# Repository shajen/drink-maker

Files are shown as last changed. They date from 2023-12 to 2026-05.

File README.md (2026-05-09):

# Introduction

The project is to build a device for automatically pouring vodka into glasses that move on wooden toy tracks.

# Presentation video

Video (http://www.youtube.com/watch?v=X1K5z6y2sik "Video")

# Quickstart

## 3D files

Parts to print available [here](3d/).

## Needed hardware

- `ESP32 C3 super mini` board with Li-Ion 18650
- `ST7789` OLED 2.0" `SPI` 240x320
- `VL53L0X` time of flight distance sensor `I2C`
- `MAX17043` battery fuel gauge `I2C`
- 5 V relay module
- 5 V mini pump
- voltage divider between battery and A0
- silicone tube

## Pinout

| Description | ESP32 C3 PIN |
| --- | --- |
| I2C SCL | GPIO9 |
| I2C SDA | GPIO8 |
| Relay | GPIO0 |
| LCD CS | GPIO5 |
| LCD DC | GPIO6 |
| LCD MOSI | GPIO10 |
| LCD SCLK | GPIO1 |
| LCD RST | GPIO7 |

## Flash

```
platformio run -t buildfs
platformio run -t uploadfs
platformio run -t upload
```

## Settings

Connect your mobile phone or PC to WiFi:  
network name: `Vodka`  
password: `12345678`

Then open [http://vodka.local/](http://vodka.local/).

| | | |
| --- | --- | --- |
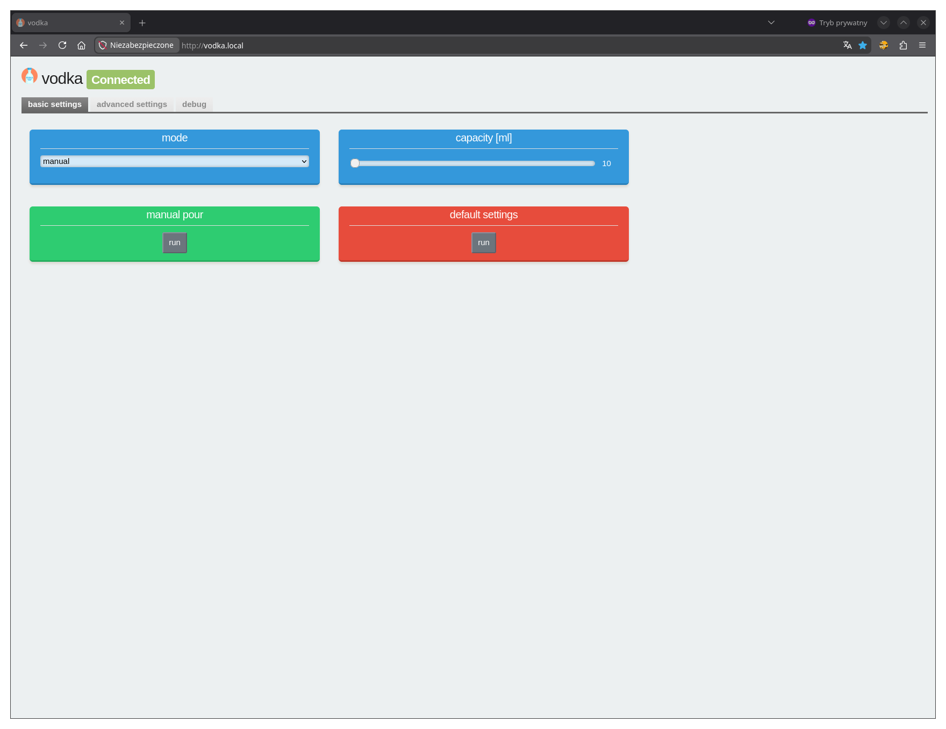
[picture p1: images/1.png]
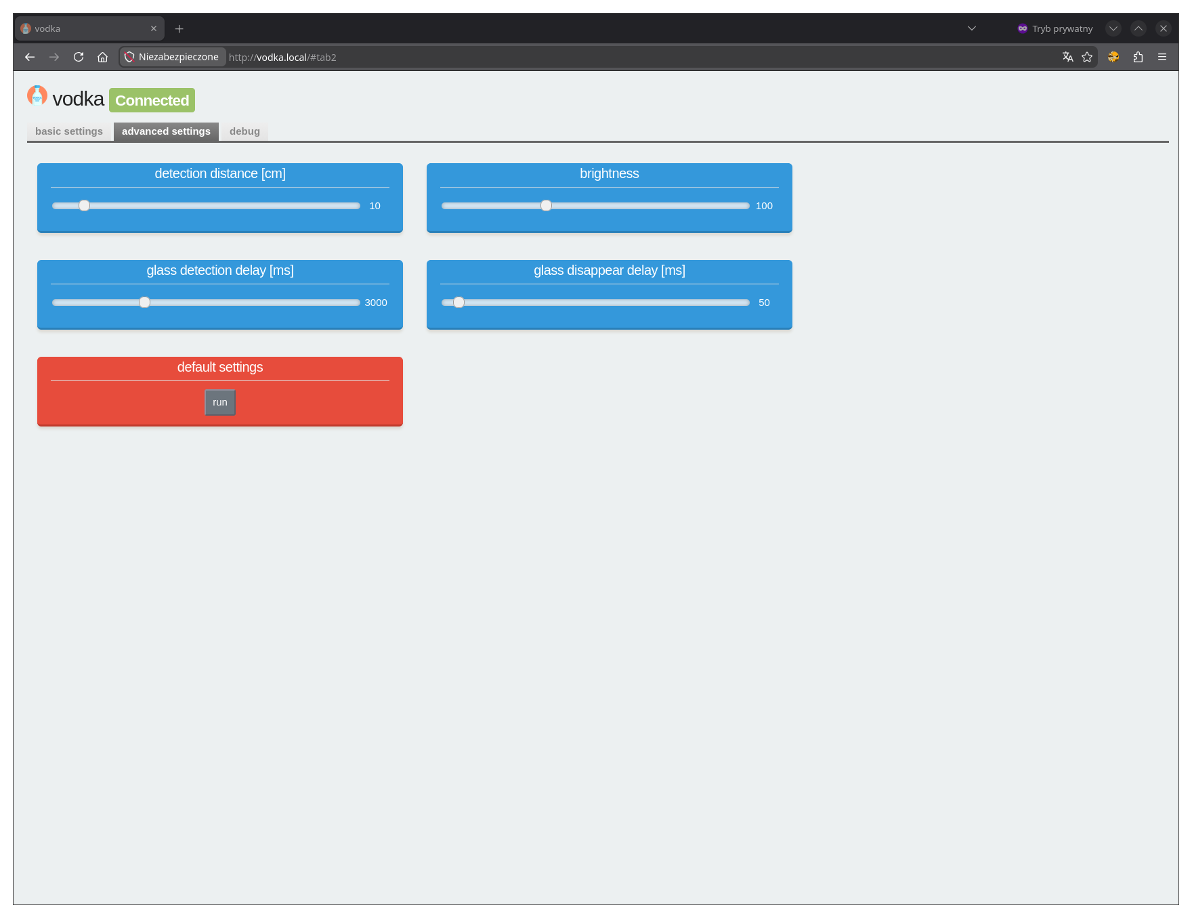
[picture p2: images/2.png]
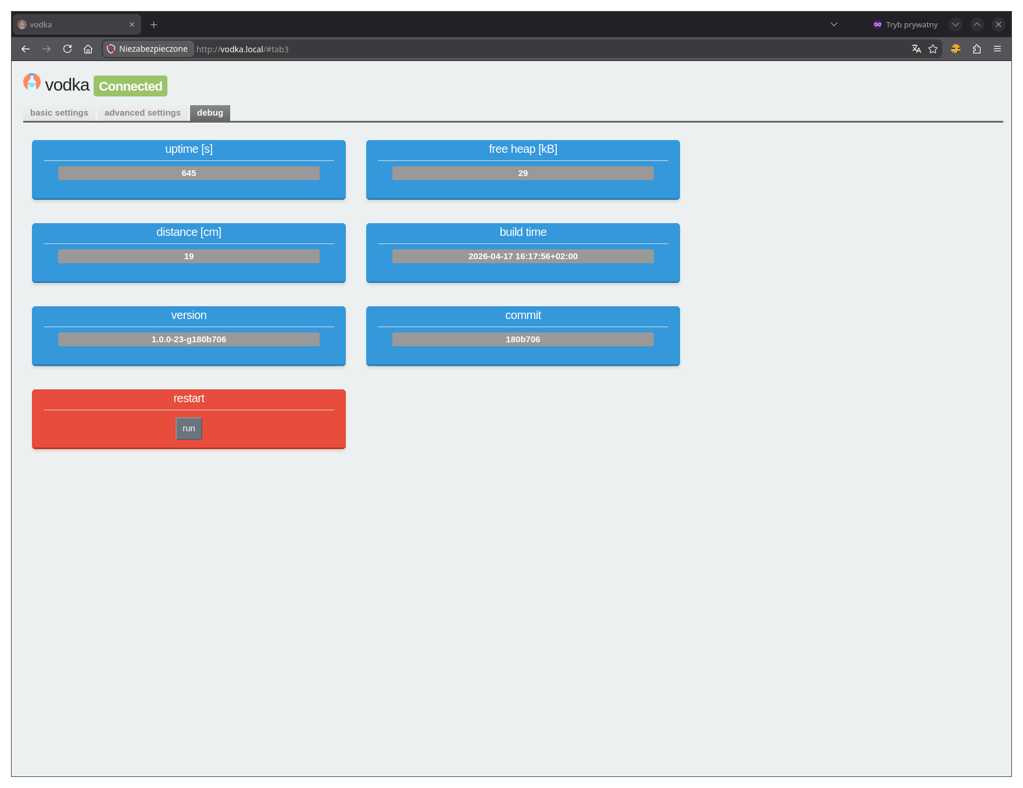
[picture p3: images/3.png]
|  |  |  |
 
# Contributing

In general don't be afraid to send pull request. Use the "fork-and-pull" Git workflow.

1. **Fork** the repo
2. **Clone** the project to your own machine
3. **Commit** changes to your own branch
4. **Push** your work back up to your fork
5. Submit a **Pull request** so that we can review your changes

NOTE: Be sure to merge the **latest** from **upstream** before making a pull request!

# Donations

If you enjoy this project and want to thanks, please use follow link:

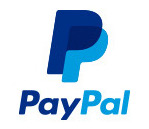
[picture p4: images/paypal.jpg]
[](https://www.paypal.com/donate/?hosted_button_id=6JQ963AU688QN)
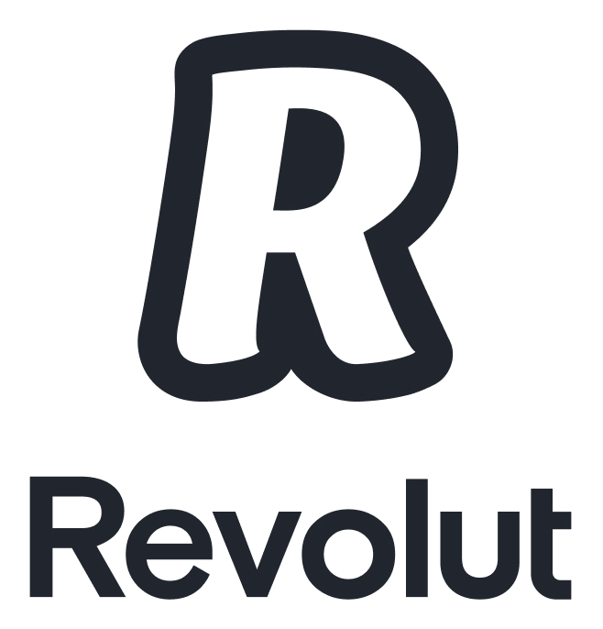
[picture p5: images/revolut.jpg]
[](https://revolut.me/borysm2b)
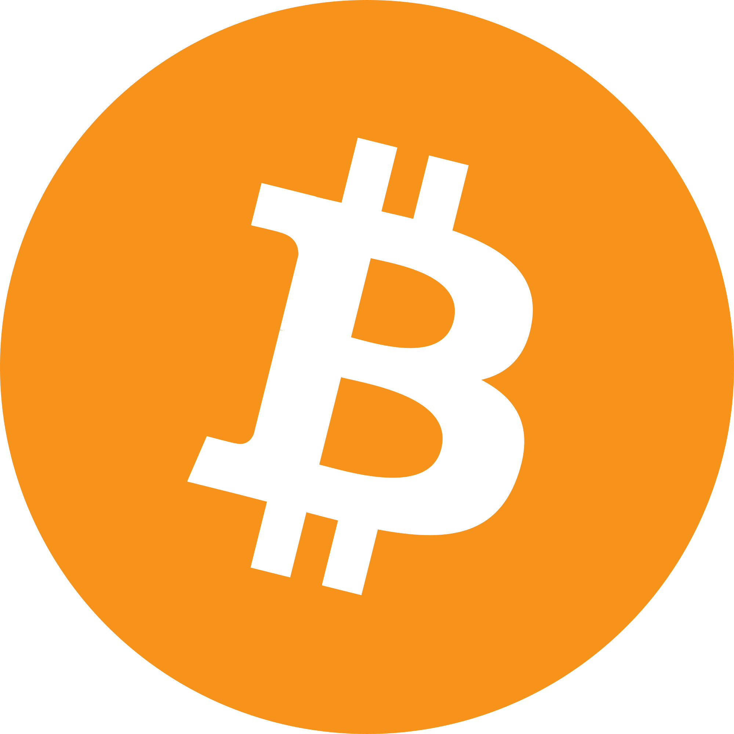
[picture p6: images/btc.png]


BTC address: 18UDYg9mu26K2E3U479eMvMZXPDpswR7Jn

# License



- *[GPLv3 license](https://www.gnu.org/licenses/gpl.html)*

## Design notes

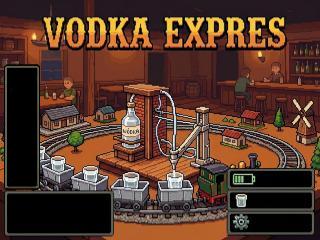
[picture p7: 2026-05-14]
images/background.jpeg

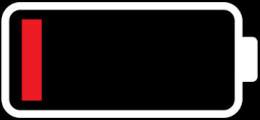
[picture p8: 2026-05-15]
images/low_battery.jpg

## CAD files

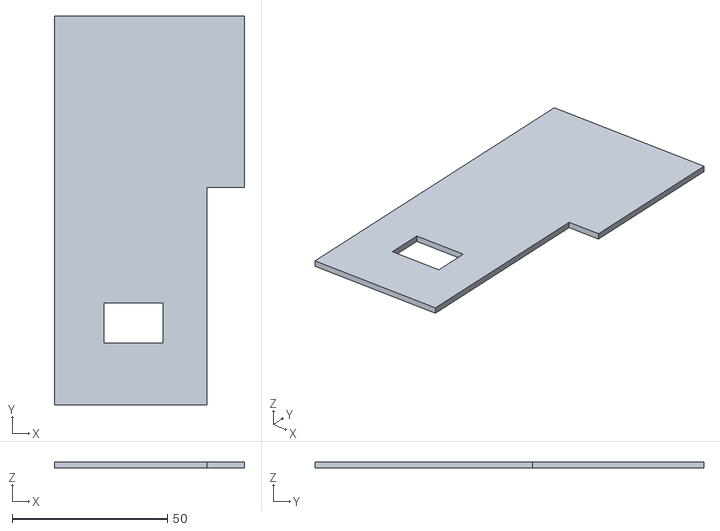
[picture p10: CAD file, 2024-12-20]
3d/drink_maker.stl
61.2 x 125.2 x 2.00

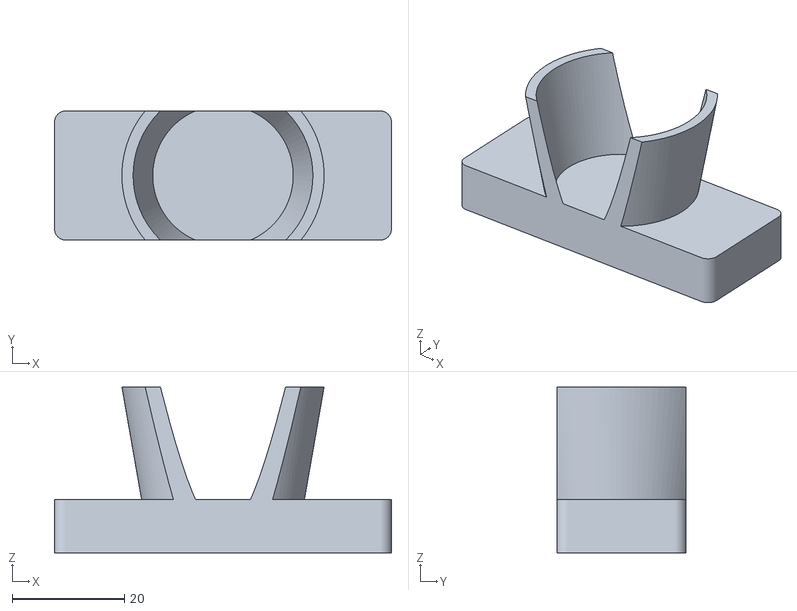
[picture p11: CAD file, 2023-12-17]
3d/wagon_container_aluminium_glass.stl
60.0 x 23.0 x 29.5

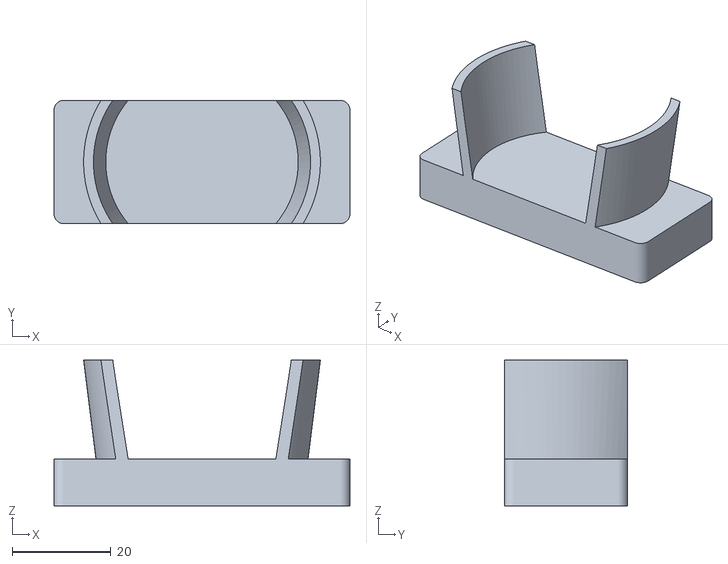
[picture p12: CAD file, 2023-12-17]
3d/wagon_container_ikea_glass.stl
60.0 x 25.0 x 29.5

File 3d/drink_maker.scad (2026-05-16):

include <pipe.scad>
include <generic.scad>
include <roundedcube.scad>
include <straigt_track.scad>

$fn = 100;
MARGIN = 0.01;
ROUND = 1.5;
WALL = 2.0;
LID_STEP = 1.0;
LID_MARGIN = 0.4;

WIDTH = 90 + 4 * WALL;
DEPTH = 120 + 4 * WALL;
HEIGHT = 52;

PIPE_IN_DIA = 6.6;
PIPE_OUT_DIA = 9.8;
PIPE_MOUNT_DIA = 10.0;
PIPE_CONNECTOR_LENGTH = 10;
PIPE_DEPTH_OFFSET = 73;
PIPE_BEND_R = 20;
PIPE_A = 110;
PIPE_B = 86;
PIPE_C = 50;

DS_DEPTH = 15;
DS_DEPTH_OFFSET = PIPE_DEPTH_OFFSET + DS_DEPTH + 5 + PIPE_MOUNT_DIA;
DS_HEIGHT = 8;
DS_HEIGHT_OFFSET = 26;

LCD_DEPTH = 52;
LCD_DEPTH_OFFSET = 22 + 18;
LCD_HEIGHT = 35.8;
LCD_HEIGHT_OFFSET = 10;

ESP_CABLE_DEPTH = 13.0;
ESP_CABLE_HEIGHT = 4.5;
ESP_CABLE_DEPTH_OFFSET = 82;
ESP_CABLE_HEIGHT_OFFSET = 36;

BASE_HEIGHT = 12;
BASE_WALL = 2;
BASE_MARGIN = 0.4;

TRACK_DISTANCE = 40;
TRACK_MARGIN = 2;

SWITCH_R = 6.4;
SWITCH_DEPTH_OFFSET = 110;
SWITCH_HEIGHT_OFFSET = 36;

MOUNTPOINT_SIZE = 6;
MOUNTPOINT_R = 1.5;
MOUNTPOINT_HEIGHT = 12;
SUPPORT_HEIGHT = 12;

PCB_MOUNTPOINT_USB_WIDTH_OFFSET = 10;
PCB_MOUNTPOINT_WIDTH_OFFSET = 43.3;
PCB_MOUNTPOINT_DEPTH_OFFSET = 28.3;
PCB_MOUNTPOINT_HEIGHT = 10;
PCB_MOUNTPOINT_BORDER_SIZE = 2;
PCB_WIDTH = 81;
PCB_DEPTH = 55.4;

BATTERY_WIDTH = 78.0;
BATTERY_DEPTH = 41.4;
BATTERY_HEIGHT = 20;
BATTERY_WALL = 2;
BATTERY_WIDTH_OFFSET = -BATTERY_WALL;
BATTERY_DEPTH_OFFSET = PCB_DEPTH;

module pcb_mountpoint(x, y, h, r1, r2) {
  translate([WALL + x, WALL + y, WALL]) {
    difference() {
      cylinder(h=h, r=r1);
      cylinder(h=h + MARGIN, r=r2);
    }
  }
}

module window(depth, height, depth_offset, height_offset) {
  translate([WALL + WIDTH - MARGIN, WALL + depth_offset - depth / 2, WALL + height_offset])
    cube([WALL + 2 * MARGIN, depth, height]);
}

module window2(depth, height, depth_offset, height_offset) {
  translate([-MARGIN, WALL + depth_offset - depth / 2, WALL + height_offset])
    cube([WALL + 2 * MARGIN, depth, height]);
}

module circle2(radius, depth_offset, height_offset) {
  translate([-MARGIN, depth_offset, height_offset + radius])
    rotate([0, 90, 0])
      cylinder(h=WALL + 2 * MARGIN, r=radius);
}

module single_support() {
  x = MOUNTPOINT_SIZE;
  h = SUPPORT_HEIGHT;
  translate([-MOUNTPOINT_SIZE / 2, -MOUNTPOINT_SIZE / 2, 0])
    polyhedron(
      points=[
        [0, 0, 0],
        [x, 0, 0],
        [0, 0, h],
        [x, 0, h],
        [x, x, h],
        [0, x, h],
      ],
      faces=[
        [0, 1, 3, 2],
        [1, 4, 3],
        [0, 5, 4, 1],
        [0, 2, 5],
        [2, 3, 4, 5],
      ],
      convexity=10
    );
}

module support(degree) {
  translate([MOUNTPOINT_SIZE / 2, MOUNTPOINT_SIZE / 2, 0]) rotate([0, 0, degree]) single_support();
  translate([MOUNTPOINT_SIZE / 2, MOUNTPOINT_SIZE / 2, 0]) rotate([0, 0, degree + 90]) single_support();
}

module mountpoint(x, y, degree) {
  translate([x + WALL, y + WALL, HEIGHT + WALL - SUPPORT_HEIGHT - MOUNTPOINT_HEIGHT]) {
    support(degree);
    translate([0, 0, SUPPORT_HEIGHT]) {
      difference() {
        cube([MOUNTPOINT_SIZE, MOUNTPOINT_SIZE, MOUNTPOINT_HEIGHT]);
        translate([MOUNTPOINT_SIZE / 2, MOUNTPOINT_SIZE / 2, 0])
          cylinder(h=MOUNTPOINT_HEIGHT + MARGIN, r=MOUNTPOINT_R);
      }
    }
  }
}

module shape(height, margin) {
  difference() {
    cube([WIDTH + 2 * margin, DEPTH + 2 * margin, height]);
    translate([WIDTH - WALL - PIPE_MOUNT_DIA + 2 * margin, PIPE_DEPTH_OFFSET + 2 * margin, -MARGIN]) cube(
        [
          PIPE_MOUNT_DIA + 2 * WALL + MARGIN + margin,
          PIPE_MOUNT_DIA + 4 * WALL - 2 * margin,
          height + 2 * MARGIN,
        ]
      );
  }
}

module main() {
  difference() {
    roundedcube([2 * WALL + WIDTH, 2 * WALL + DEPTH, 2 * WALL + HEIGHT], false, ROUND, "z");
    translate([WALL - LID_STEP, WALL - LID_STEP, WALL + HEIGHT]) shape(WALL + MARGIN, LID_STEP);
    translate([WALL, WALL, WALL]) shape(HEIGHT + WALL + MARGIN, 0);

    window(LCD_DEPTH, LCD_HEIGHT, LCD_DEPTH_OFFSET, LCD_HEIGHT_OFFSET);
    window(DS_DEPTH, DS_HEIGHT, DS_DEPTH_OFFSET, DS_HEIGHT_OFFSET);

    window2(
      ESP_CABLE_DEPTH, ESP_CABLE_HEIGHT, ESP_CABLE_DEPTH_OFFSET,
      ESP_CABLE_HEIGHT_OFFSET
    );
    circle2(SWITCH_R, SWITCH_DEPTH_OFFSET, SWITCH_HEIGHT_OFFSET);

    translate(
      [WALL + WIDTH - PIPE_MOUNT_DIA / 2, PIPE_DEPTH_OFFSET + PIPE_MOUNT_DIA / 2 + 3 * WALL, WALL + HEIGHT - PIPE_CONNECTOR_LENGTH]
    )
      pipe(0, PIPE_MOUNT_DIA, PIPE_CONNECTOR_LENGTH + WALL + MARGIN);

    translate([WIDTH - PIPE_MOUNT_DIA - MARGIN, PIPE_DEPTH_OFFSET + 3 * WALL, WALL + MARGIN])
      cube([PIPE_MOUNT_DIA + WALL, PIPE_MOUNT_DIA, HEIGHT - PIPE_CONNECTOR_LENGTH - WALL]);
  }
  mountpoint(0, 0, 270);
  mountpoint(0, DEPTH - 3 * WALL, 180);
  mountpoint(WIDTH - 3 * WALL, DEPTH - 3 * WALL, 90);
  mountpoint(WIDTH - 3 * WALL, 0, 0);

  pcb_mountpoint(PCB_MOUNTPOINT_USB_WIDTH_OFFSET + PCB_MOUNTPOINT_WIDTH_OFFSET, PCB_MOUNTPOINT_DEPTH_OFFSET, PCB_MOUNTPOINT_HEIGHT, 7, 1.5);
  translate([WALL + PCB_MOUNTPOINT_USB_WIDTH_OFFSET, WALL, WALL])
    difference() {
      cube([PCB_WIDTH, PCB_DEPTH, PCB_MOUNTPOINT_HEIGHT]);
      translate([PCB_MOUNTPOINT_BORDER_SIZE, PCB_MOUNTPOINT_BORDER_SIZE, MARGIN])
        cube([PCB_WIDTH - 2 * PCB_MOUNTPOINT_BORDER_SIZE, PCB_DEPTH - 2 * PCB_MOUNTPOINT_BORDER_SIZE, PCB_MOUNTPOINT_HEIGHT]);
    }

  translate([WALL + BATTERY_WIDTH_OFFSET, WALL + BATTERY_DEPTH_OFFSET, WALL])
    difference() {
      cube([BATTERY_WIDTH + 2 * BATTERY_WALL, BATTERY_DEPTH + 2 * BATTERY_WALL, BATTERY_HEIGHT]);
      translate([BATTERY_WALL, BATTERY_WALL, MARGIN])
        cube([BATTERY_WIDTH, BATTERY_DEPTH, BATTERY_HEIGHT]);
    }
}

module lid() {
  difference() {
    shape(WALL, LID_STEP - LID_MARGIN);
    translate([LID_STEP + MOUNTPOINT_SIZE / 2, LID_STEP + MOUNTPOINT_SIZE / 2, 0]) {
      custom_cylinder(outside_radius=1.5, height=WALL + 2 * MARGIN);
      translate([WIDTH - MOUNTPOINT_SIZE, 0])
        custom_cylinder(outside_radius=1.5, height=WALL + 2 * MARGIN);
      translate([WIDTH - MOUNTPOINT_SIZE, DEPTH - MOUNTPOINT_SIZE, 0])
        custom_cylinder(outside_radius=1.5, height=WALL + 2 * MARGIN);
      translate([0, DEPTH - MOUNTPOINT_SIZE, 0])
        custom_cylinder(outside_radius=1.5, height=WALL + 2 * MARGIN);
    }
  }
}

module base() {
  difference() {
    roundedcube(
      [WIDTH + 2 * (BASE_WALL + WALL), DEPTH + 2 * (BASE_WALL + WALL), BASE_HEIGHT + BASE_WALL], false,
      ROUND, "z"
    );
    translate([BASE_WALL - BASE_MARGIN, BASE_WALL - BASE_MARGIN, BASE_HEIGHT])
      cube([WIDTH + 2 * (BASE_MARGIN + WALL), DEPTH + 2 * (BASE_MARGIN + WALL), BASE_WALL + MARGIN]);
    translate([2 * BASE_WALL, 2 * BASE_WALL, -MARGIN])
      cube([WIDTH + 2 * (WALL - BASE_WALL), DEPTH + 2 * (WALL - BASE_WALL), BASE_HEIGHT + 2 * MARGIN]);
  }

  X = 2 * (BASE_WALL + WALL);
  TRACK_LENGTH = DEPTH + 2 * (BASE_WALL + WALL);

  translate([WIDTH + X - TRACK_MARGIN, 0, 0]) cube([TRACK_DISTANCE + 2 * TRACK_MARGIN, DEPTH + X, WALL]);
  translate([WIDTH + X + TRACK_DISTANCE, TRACK_LENGTH, 0]) rotate([0, 0, 270])
      straigt_track(TRACK_LENGTH, false, left_connector="male", right_connector="female");
}

module pipe_u() {
  X = PIPE_BEND_R + PIPE_OUT_DIA / 2;
  Y = PIPE_BEND_R + PIPE_OUT_DIA / 2;

  A = PIPE_A - Y;
  B = PIPE_B - 2 * Y;
  C = PIPE_C - Y;

  translate([PIPE_OUT_DIA / 2, 0, X]) pipe(PIPE_IN_DIA, PIPE_OUT_DIA, A);
  translate([X, 0, X]) rotate([270, 0, 180]) pipe_90(PIPE_IN_DIA, PIPE_OUT_DIA, 0, PIPE_BEND_R);
  translate([X, 0, PIPE_OUT_DIA / 2]) rotate([0, 90, 0]) pipe(PIPE_IN_DIA, PIPE_OUT_DIA, B);
  translate([X + B, 0, X]) rotate([270, 0, 0]) pipe_90(PIPE_IN_DIA, PIPE_OUT_DIA, 0, PIPE_BEND_R);
  translate([B + 2 * X - PIPE_OUT_DIA / 2, 0, X]) pipe(PIPE_IN_DIA, PIPE_OUT_DIA, C);
}

translate([0 * (WIDTH + 10), 0, 0]) main();
translate([1 * (WIDTH + 10), 0, 0]) lid();
translate([2 * (WIDTH + 10), 0, 0]) base();
translate([3 * (WIDTH + 10) + TRACK_DISTANCE + 40 + 4 * WALL, 0, 0]) pipe_u();

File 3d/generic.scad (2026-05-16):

MARGIN = 0.01;

module custom_cylinder(outside_radius, height, inside_radius = 0) {
  difference() {
    cylinder(h=height, r=outside_radius);
    if (0 < inside_radius) {
      translate([0, 0, -MARGIN])
        cylinder(h=height + 2 * MARGIN, r=inside_radius);
    }
  }
}

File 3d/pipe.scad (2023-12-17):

module pipe(inside_dia, outside_dia, height)
{
    linear_extrude(height = height, center = false) difference()
    {
        circle(r = outside_dia / 2, $fn = 100);
        circle(r = inside_dia / 2, $fn = 100);
    }
}

module pipe_90(in_dia, out_dia, length, bend_radius)
{
    X = 0; // bend_radius * sqrt(2);
    translate([ -X / 2, -X / 2, 0 ])
    {
        rotate_extrude(angle = 90, convexity = 10) translate([ bend_radius, 0, 0 ]) difference()
        {
            circle(r = out_dia / 2);
            circle(r = in_dia / 2);
        }
        translate([ -length, bend_radius, 0 ]) rotate([ 0, 90, 0 ]) pipe(in_dia, out_dia, length);
        translate([ bend_radius, 0, 0 ]) rotate([ 90, 0, 0 ]) pipe(in_dia, out_dia, length);
    }
}

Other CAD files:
3d/straigt_track.scad
3d/roundedcube.scad
3d/wagon_container.scad

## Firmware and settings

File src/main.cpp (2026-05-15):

#include <Wire.h>
#include <config.h>
#include <logger.h>
#include <low_battery_controller.h>
#include <main_controller.h>

#include <memory>

std::unique_ptr<Thread> thread;

void setup() {
  Serial.begin(UART_BAUDRATE);
  Serial.printf("\n");
  log("main", "init");
  log("main", "hostname: %s, build time: %s, version: %s, commit: %s", HOSTNAME, BUILD_TIME, GIT_TAG, GIT_COMMIT);
  Wire.begin(SDA_PIN, SCL_PIN);
  LittleFS.begin();

  BatteryController batteryController;
  if (batteryController.isLowBattery()) {
    thread = std::make_unique<LowBatteryController>();
  } else {
    thread = std::make_unique<MainController>();
  }
}

void loop() {
  delay(1);
  thread->loop(std::chrono::milliseconds(millis()));
}

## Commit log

2023-12-16 Replaced polish menu with english.
    [pouring_controller.cpp]
2023-12-17 Added 3D files.
    [drink_maker.scad, drink_maker.stl, pipe.scad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]
2024-12-20 Added switch to lid.
    [drink_maker.scad, drink_maker.stl]
2025-01-23 Removed buttons.
2025-01-28 Updated 3d model.
    [drink_maker.scad]
2025-02-11 Added manual pour button.
2025-04-01 Added battery level.
2025-04-04 Fixed initial battery voltage, made voltage reading more stable.
2025-04-09 Show battery on display.
2025-04-12 Round battery percentage to int.
2025-04-19 Migrate to ESP32.
2025-04-21 Switch do esp32 c3.
2026-04-26 Added custom partitions.
    [partitions.csv]
2026-05-06 Updated pump.
2026-05-06 Updated I2C pin.
2026-05-07 Removed led controller.
2026-05-10 Stop pump if settings changed.
2026-05-12 Optimized BatteryController.
2026-05-14 Reformat scad file.
    [drink_maker.scad]
2026-05-14 Refactor drink_maker.scad
    [drink_maker.scad]
2026-05-15 Limit battery percentage to 100%.
2026-05-16 Added PCB mountpoint, added battery mount, updated lid, some small size fixes.
    [drink_maker.scad, generic.scad]
2026-05-16 Updated pump factor.
2026-05-17 Updated battery_controller.
